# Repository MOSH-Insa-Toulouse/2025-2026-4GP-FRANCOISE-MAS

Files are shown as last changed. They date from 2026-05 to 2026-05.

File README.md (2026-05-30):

 # Capteur de déformation en graphite - Projet 4GP

  > **Génie Physique - INSA Toulouse - Promotion 2025-2026**
  > UF « Du capteur au banc de test »

  ## Sommaire
  - [Présentation générale](#présentation-générale)
  - [1. Le capteur graphite](#1-le-capteur-graphite)
    - [1.1 Principe physique](#11-principe-physique)
    - [1.2 Objectifs et livrables](#12-objectifs-et-livrables)
    - [1.3 Matériel](#13-matériel)
  - [2. Conditionnement du signal](#2-conditionnement-du-signal)
    - [2.1 Étage transimpédance (LTSpice)](#21-étage-transimpédance-ltspice)
    - [2.2 Modèle mathématique](#22-modèle-mathématique)
  - [3. Carte électronique (shield Arduino)](#3-carte-électronique-shield-arduino)
    - [3.1 Routage sous KiCad](#31-routage-sous-kicad)
    - [3.2 Fabrication et brochage](#32-fabrication-et-brochage)
  - [4. Logiciel embarqué](#4-logiciel-embarqué)
  - [5. Application mobile](#5-application-mobile)
  - [6. Banc de caractérisation](#6-banc-de-caractérisation)
  - [7. Résultats et analyse](#7-résultats-et-analyse)
  - [8. Bilan et perspectives](#8-bilan-et-perspectives)
  - [Remerciements](#remerciements)
  - [Contacts](#contacts)

  ---

  ## Présentation générale

  Ce projet propose une chaîne de mesure complète - acquisition, traitement, affichage et
  archivage des résultats - construite autour d'un capteur de déformation **low-tech** : une simple piste
  de graphite tracée au crayon sur du papier.

  L'ensemble s'appuie sur l'article de **Lin, C.-W., Zhao, Z., Kim, J. et al. (2014)**,
  *« Pencil Drawn Strain Gauges and Chemiresistors on Paper »* (Nature). L'article de
  référence est disponible dans le dépôt.

  On cherche ic à faire un dispositif **bon marché,
  reproductible, réparable et fabricable avec des moyens d'atelier ordinaires**, tout en
  restant exploitable scientifiquement.

  ---

  ## 1. Le capteur graphite

  ### 1.1 Principe physique

  Le capteur est obtenu en frottant un crayon sur une feuille de papier (≈ 0,35 mm
  d'épaisseur). Le graphite s'accroche aux fibres et forme un réseau granulaire : le
  courant circule par les contacts entre grains et par effet tunnel entre particules
  voisines. La résistance du tracé dépend donc directement de la distance entre grains.

  Lorsque le papier est plié, cette distance évolue :

  | Sollicitation | Effet sur le réseau | Résistance |
  |---------------|---------------------|------------|
  | **Traction**  | Les grains s'écartent | **augmente** |
  | **Compression** | Les grains se rapprochent | **diminue** |

  La sensibilité dépend de plusieurs facteurs : dureté de la mine, quantité de graphite
  déposée, géométrie du tracé, humidité et température ambiantes. Différentes duretés ont
  été testées (2H, HB, B, 3B, 4B, 6B) afin de comparer leur comportement.

  ### 1.2 Objectifs et livrables

  L'objectif est de remonter à l'angle de flexion (donc à la déformation) à partir de la
  seule mesure de résistance. Le travail se décompose en cinq étapes : simulation du
  conditionnement analogique, conception du PCB, programmation du microcontrôleur,
  développement de l'application mobile et caractérisation expérimentale.

  Livrables produits :
  - un **shield Arduino** regroupant l'électronique de mesure, d'amplification et de
    communication.
  - un **code Arduino (C++)** organisé en pseudo machine à états (car nous avons essayer mais ce n'est pas réellement une machine à état).
  - une **IHM (interface human machine) en format .py** de supervision et de tracé temps réel.
  - une **datasheet** récapitulant la caractérisation du capteur.

  ### 1.3 Matériel

  **Électronique**
  - Arduino UNO Rev 3
  - Amplificateur opérationnel LTC1050
  - Potentiomètre numérique SPI MCP41010 (10 kΩ, 256 pas)
  - Écran OLED 0,96" SSD1306 (I²C)
  - Encodeur rotatif KY-040
  - Module Bluetooth HC-05
  - Passifs : résistances (2×1 kΩ, 1×10 kΩ, 2×100 kΩ) et condensateurs (2×100 nF, 1×1 µF)
  - Pour comparaison : capteur de flexion commercial (Flex Sensor) + résistance de charge 47 kΩ

  **Fabrication du capteur**
  - Papier souple, crayons de duretés variées, contacts et pinces de test Mueller

  **Logiciels**
  - LTSpice (simulation) · KiCad (PCB) · Arduino IDE (firmware)

  **Banc d'essai**
  - module imprimé en 3D à rayons de courbure étalonnés + instrumentation de mesure. Nous avons réutilisé les système imprimés les années passées pour rester dans la démarche **low-tech**

  ---

  ## 2. Conditionnement du signal

  ### 2.1 Étage transimpédance (LTSpice)

  À vide, le capteur affiche une résistance très élevée (du MΩ au GΩ selon la mine).
  Sous 5 V, le courant traversant n'est que de l'ordre du nanoampère : il faut donc un
  étage d'amplification pour ramener le signal dans la plage 0–5 V de l'ADC de l'Arduino.

  Un montage **transimpédance** autour du LTC1050 a été simulé sous LTSpice afin de valider
  le gain, étudier la réponse en fréquence et dimensionner le filtrage. Trois filtres
  passe-bas améliorent le rapport signal/bruit :

  1. **Entrée (~175 Hz)** — atténue les vibrations et tremblements mécaniques ;
  2. **Rétroaction active (~1,6 Hz)** — coupe le bruit secteur 50 Hz ;
  3. **Sortie (~1,6 kHz)** — supprime les parasites haute fréquence de l'électronique
     numérique.

  <p align="center">
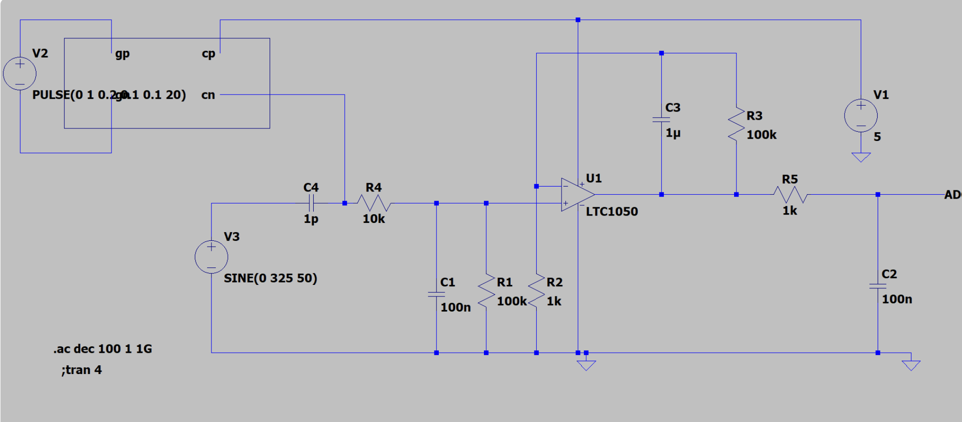
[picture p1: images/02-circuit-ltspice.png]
Schéma du montage transimpédance simulé sous LTSpice
    
    <br><em>Montage transimpédance autour du LTC1050 simulé sous LTSpice.</em>
  </p>

  ### 2.2 Modèle mathématique

  La tension lue par l'ADC s'écrit :

  $$V_{ADC} = \left(1 + \frac{R_3}{R_2}\right) \cdot \frac{R_1}{R_1 + R_c + R_5} \cdot V_{cc}$$

  ce qui permet au firmware de remonter à la résistance du capteur :

  $$R_c = \left(1 + \frac{R_3}{R_2}\right) \cdot R_1 \cdot \frac{V_{cc}}{V_{ADC}} - R_1 - R_5$$

  La résistance $R_2$ est pilotée dynamiquement par le potentiomètre numérique MCP41010,
  ce qui rend possible l'auto-calibration décrite plus bas.

  ---

  ## 3. Carte électronique (shield Arduino)

  ### 3.1 Routage sous KiCad

  Une fois le montage validé en simulation, le PCB a été dessiné sous KiCad pour se
  brancher directement sur l'Arduino UNO. Il a fallu créer les symboles et empreintes des
  composants absents des bibliothèques standard (Bluetooth, potentiomètre numérique…),
  puis assembler le schéma en respectant les bus **SPI** et **I²C**.

  Le placement a cherché à raccourcir les pistes analogiques et à limiter les couplages.

  <p align="center">
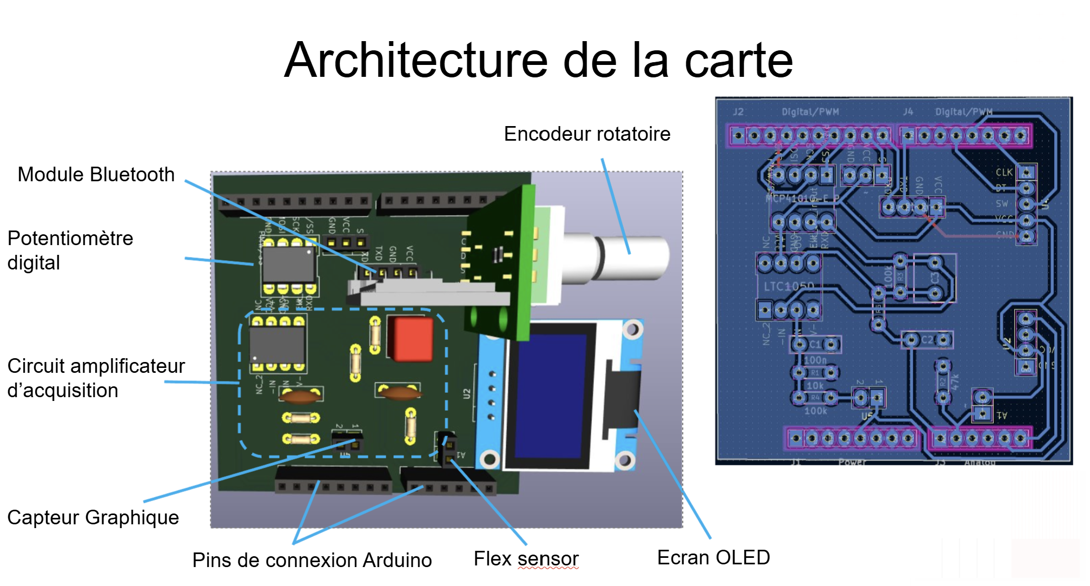
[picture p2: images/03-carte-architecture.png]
Architecture de la carte : rendu 3D annoté et routage PCB sous KiCad
    
    <br><em>Architecture de la carte : rendu 3D annoté (gauche) et routage du PCB sous KiCad (droite).</em>
  </p>

  ### 3.2 Fabrication et brochage

  Le circuit a été gravé sur plaque époxy cuivrée par **photolithographie**
  (impression du masque, insolation UV, révélation, gravure au perchlorure de fer,
  perçage, soudure). *Merci à Cathy sans qui on serait sans doute encore en train de nous arracher les cheveux sur la carte.*

  Brochage retenu :

  | Composant | Rôle | Interface Arduino |
  |-----------|------|-------------------|
  | LTC1050 | Amplification transimpédance | Entrée analogique `A0` |
  | MCP41010 | Potentiomètre numérique 10 kΩ | SPI (`CS`, `MOSI: D11`, `SCK: D13`) |
  | SSD1306 | Affichage OLED | I²C (`SDA: A4`, `SCL: A5`) |
  | KY-040 | Navigation menu | Interruptions (`CLK: D2`, `DT`, `SW`) |
  | HC-05 | Liaison Bluetooth | SoftwareSerial (`RX`, `TX`) |
  | Flex Sensor | Référence commerciale | Pont diviseur (47 kΩ) |

  Des tests de continuité et de courts-circuits ont suivi l'assemblage. Une première carte
  a dû être reprise : car nous nous étions trompé avec le port qui était nécessaire aux interruptions pour le menu.

  ---

  ## 4. Logiciel embarqué

  Le firmware Arduino orchestre l'ensemble du système au moyen d'une **tentative de code de machine à états**,
  ce qui garantit un enchaînement clair des tâches :

  Fonctions principales : acquisition du signal, calcul de $R_c$, **auto-calibration** de
  la résistance à plat $R_0$ via le MCP41010 (point de repos centré à $V_{cc}/2$),
  affichage OLED, navigation par encodeur (gérée par interruptions) et transmission
  Bluetooth. Le code s'appuie sur les bibliothèques SPI, I²C et série, avec un soin
  particulier porté à la stabilité des mesures.

  ---

  ## 5. Application mobile

  Une application Android développée avec claude code dans un premier temps mais nous nous sommes rendu compte que le code était bine trop complexe pour une app qui reste assez basique. Alors nous nous sommes tournés vers une HIM python car avec nos expériences personnelles nous avions déjà été confronté à ce genre de code python pour assurer la supervision et
  l'archivage des mesures :

  - connexion au module HC-05 (sélection dans la liste, voyant d'état) ;
  - réception cadencée sur un timer de 200 ms (5 Hz) dès que des octets sont disponibles ;
  - tracé temps réel par défilement horizontal sur un `Canvas` ;
  - export des données au format `.txt` (concaténation dans une variable globale, puis
    `SaveFile`).

  L'objectif était de disposer d'une interface simple, utilisable directement pendant les
  essais.

  <p align="center">
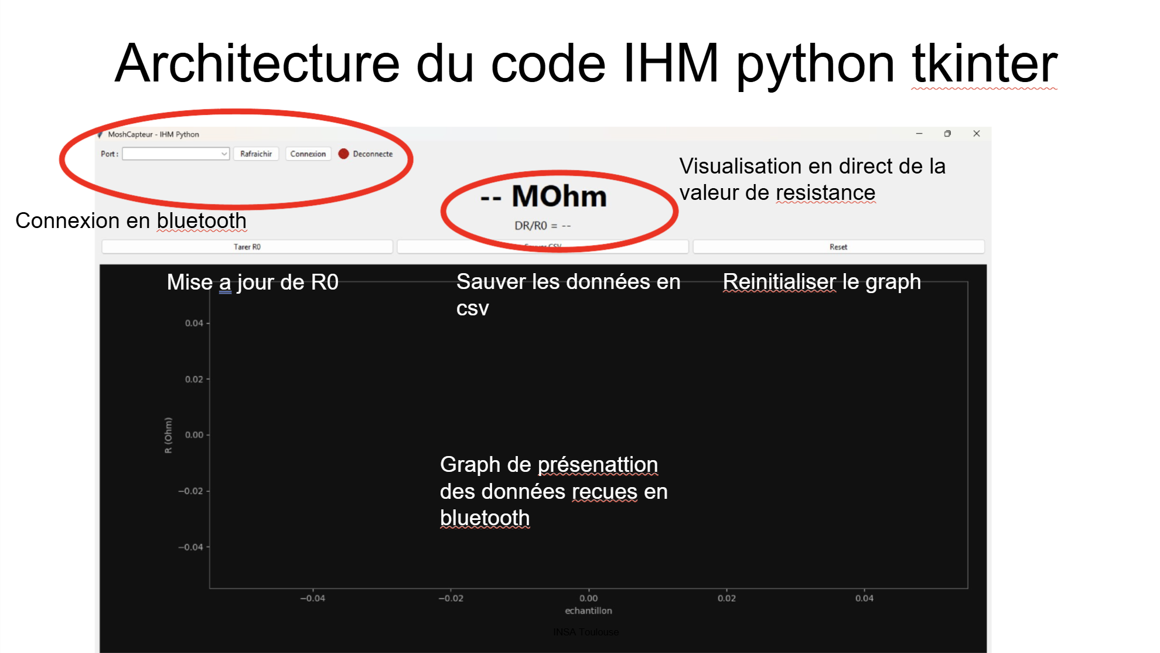
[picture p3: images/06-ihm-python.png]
Interface de supervision IHM en Python
    
    <br><em>IHM Python : connexion HC-05, tracé temps réel et export des mesures.</em>
  </p>

  ---

  ## 6. Banc de caractérisation

  Pour imposer des déformations connues, un **gabarit imprimé en 3D** a été conçu : une
  série de demi-cylindres à rayons de courbure étalonnés. Le capteur, maintenu par des
  pinces de test, y est plaqué dans deux configurations :

  - **Traction** : la piste de graphite est orientée vers l'extérieur → le maillage
    s'étire → $R_c$ augmente.
  - **Compression** : la piste est plaquée contre le cylindre → les feuillets se
    rapprochent → $R_c$ diminue.

  Chaque rayon correspond à un angle de flexion connu, ce qui permet d'étudier la
  sensibilité, la répétabilité et la réponse traction/compression pour plusieurs duretés
  de crayon.

  <p align="center">
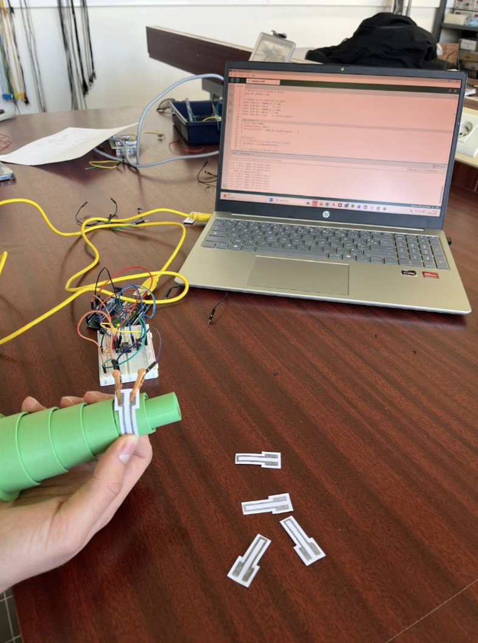
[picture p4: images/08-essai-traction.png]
Essai en traction sur le banc de caractérisation
    
    <br><em>Essai en traction : la piste de graphite est orientée vers l'extérieur.</em>
  </p>

  ---

  ## 7. Résultats et analyse

  Les mesures confirment le comportement attendu : **hausse de la résistance en traction,
  baisse en compression**, avec une forte dépendance au type de mine utilisé.

  - Les mines **tendres** (4B, 6B), riches en carbone, donnent une résistance initiale
    faible, une bonne conductivité et une réponse linéaire en compression — mais une faible
    tenue mécanique (perte de matière par frottement).
  - Les mines **plus dures** (B, 3B), plus chargées en liant, partent d'une résistance plus
    élevée et offrent un facteur de jauge supérieur, au prix d'une dérive et
    d'irrégularités caractéristiques des milieux granulaires désordonnés.

  On observe aussi que **la mesure abîme le capteur** : la résistance à plat diffère avant
  et après essai. Les acquisitions ont donc été menées en deux temps (traction puis
  compression), chacune avec sa propre *flat-band resistance*.

  <p align="center">
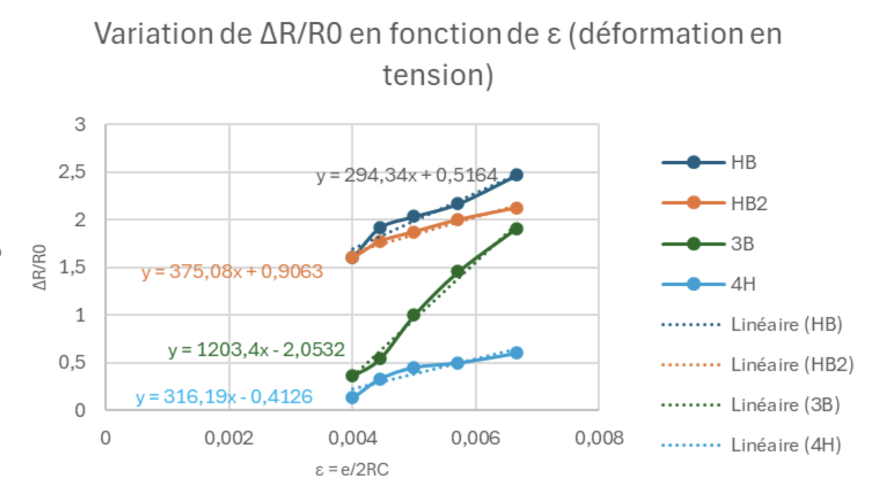
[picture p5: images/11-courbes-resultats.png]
Courbes R = f(flexion) en traction et compression
    
    <br><em>Courbes R = f(flexion/compression) pour les différentes mines.</em>
  </p>

  ---

  ## 8. Bilan et perspectives

  Le projet valide une **chaîne de mesure complète et connectée**, de la modélisation
  analogique jusqu'à l'application mobile, à partir de matériaux quasi gratuits.

  **Atouts** : coût matière négligeable, éco-conception, accessibilité, bonne réponse en
  traction/compression, faible consommation, capteur réparable sur place en repassant du
  graphite.

  **Limites** : répétabilité modeste (usure du film, contacts des pinces, hystérésis du
  papier) face aux jauges industrielles.

  Le capteur reste **exploitable à condition d'être calibré individuellement** : les
  valeurs absolues varient, mais le comportement relatif sous déformation est cohérent
  après étalonnage.

  Pistes d'amélioration vers un produit viable (capteurs jetables, usage pédagogique) :
  1. **électrodes fixes** imprimées plutôt que des contacts mécaniques ;
  2. **protection** du film par vernis/plastification, et vernis sur le PCB contre
     l'oxydation du cuivre.

  ---

  ## Remerciements

  Merci à l'équipe encadrante pour son accompagnement durant les phases de conception, de
  fabrication et de caractérisation : **J. Grisolia, B. Mestre, A. Biganzoli et
  C. Crouzet** — et tout particulièrement à Cathy Crouzet pour son aide en atelier PCB.

  ## Contacts

  N'hésitez pas à nous écrire pour toute question sur le projet ou les fichiers de
  fabrication :

  - **Ellande FRANCOISE** — `francoise@insa-toulouse.fr`
  - **Clément MAS** — `cmas@insa-toulouse.fr`

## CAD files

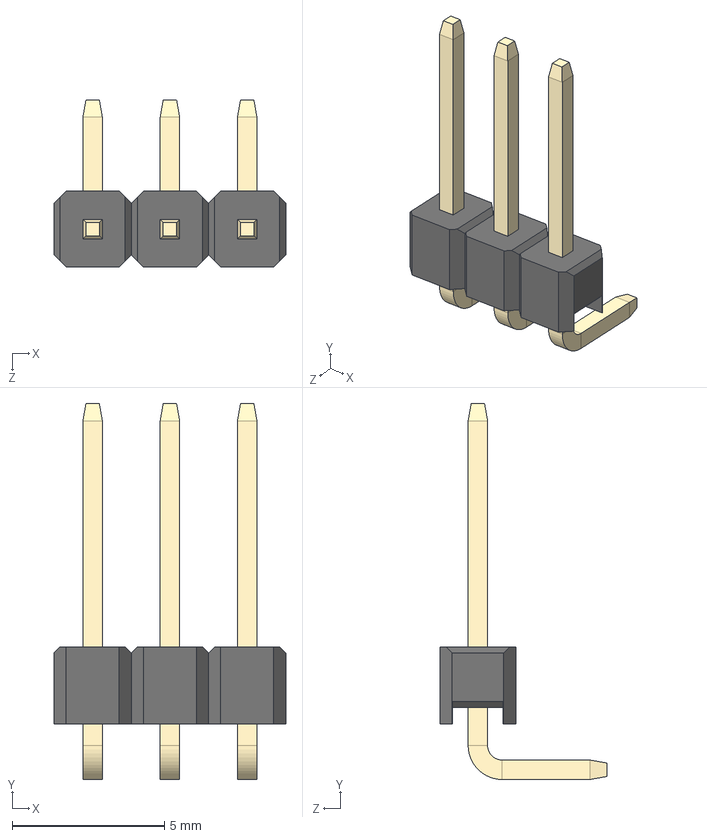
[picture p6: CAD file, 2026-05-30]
KICAD/Projet Capteur final/Composants/1x3 Male Pin Header Angle.STEP
7.63 x 12.4 x 5.50 mm

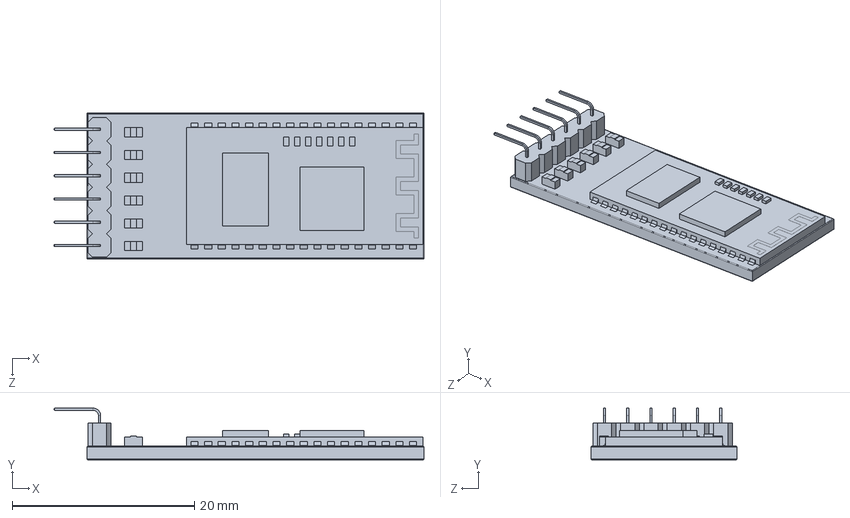
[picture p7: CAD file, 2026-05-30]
KICAD/Projet Capteur final/Composants/HC05.STEP
40.6 x 5.67 x 16.0 mm

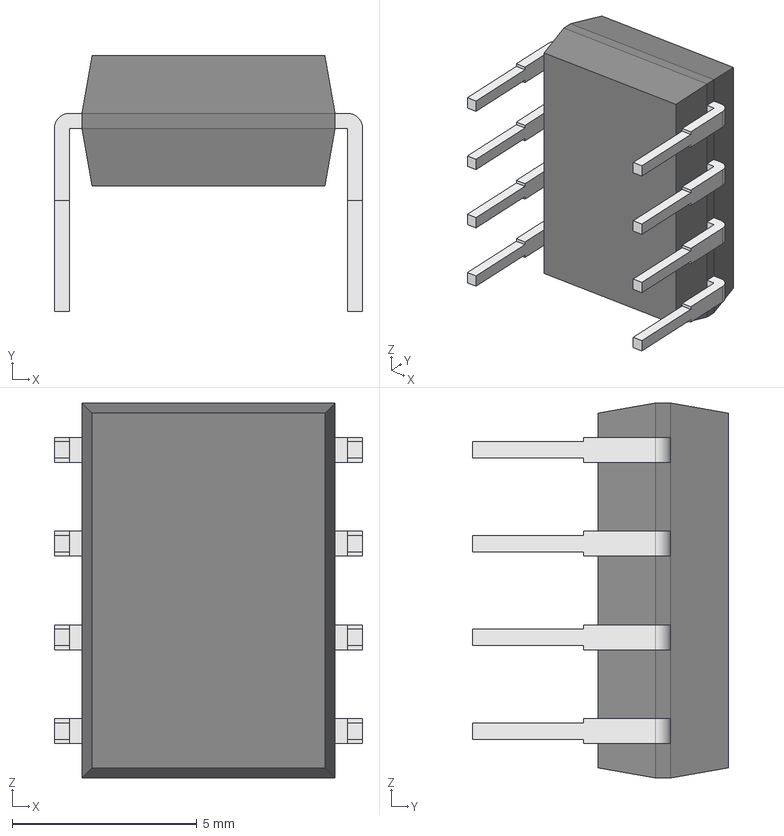
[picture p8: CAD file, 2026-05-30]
KICAD/Projet Capteur final/Composants/LTC1050ACN8.step
8.35 x 6.93 x 10.2 mm
Body001 (Mirror #1) x 5

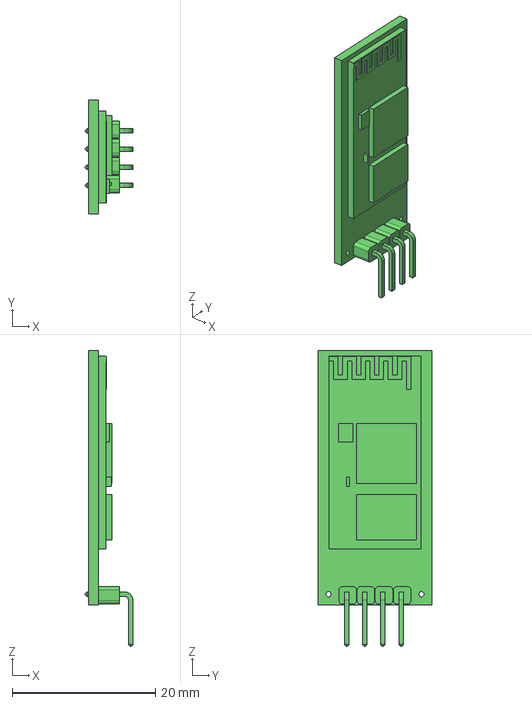
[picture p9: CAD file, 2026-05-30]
KICAD/Projet Capteur final/Composants/HC-05 Bluetooth Module.stp
6.68 x 16.0 x 41.4 mm

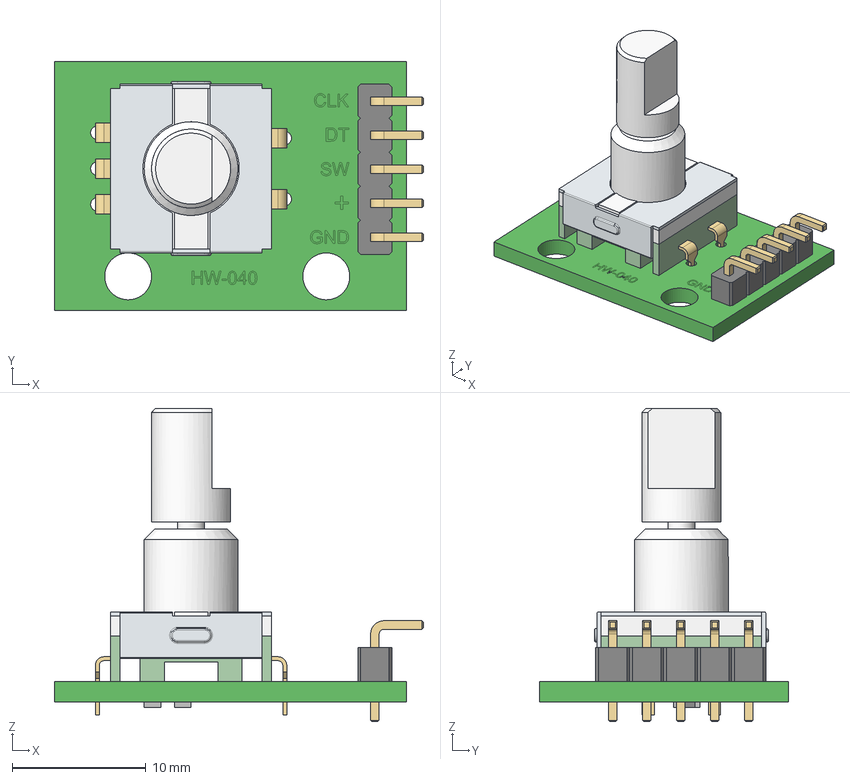
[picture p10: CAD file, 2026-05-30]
KICAD/Projet Capteur final/Composants/HW-040 Encoder module.stp
27.6 x 18.6 x 23.4 mm
Encoder PCB
Knob static part
Knob rotary part
Top plate knob
Plastic bottom knob
Encoder terminal x 5
1X5 Pin Socket
Bend pin x 5
0805 Terminal x 4
0805 Resistor Body x 2

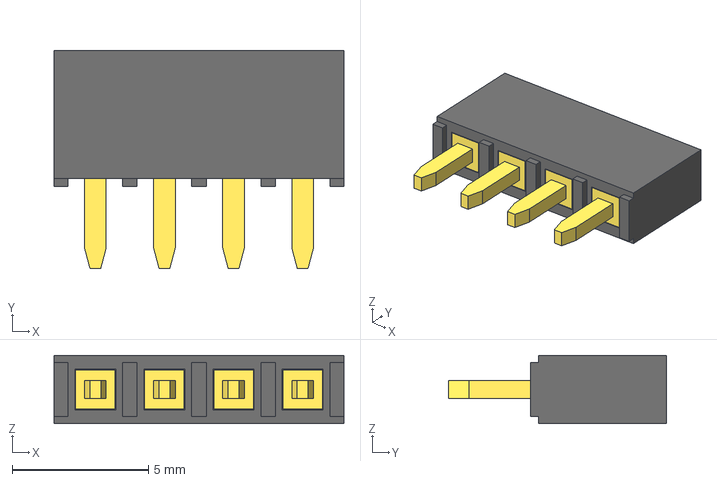
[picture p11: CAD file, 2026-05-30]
KICAD/Projet Capteur final/Composants/4-Pin Header - Female - 2.54mm (1).step
10.7 x 8.00 x 2.50 mm

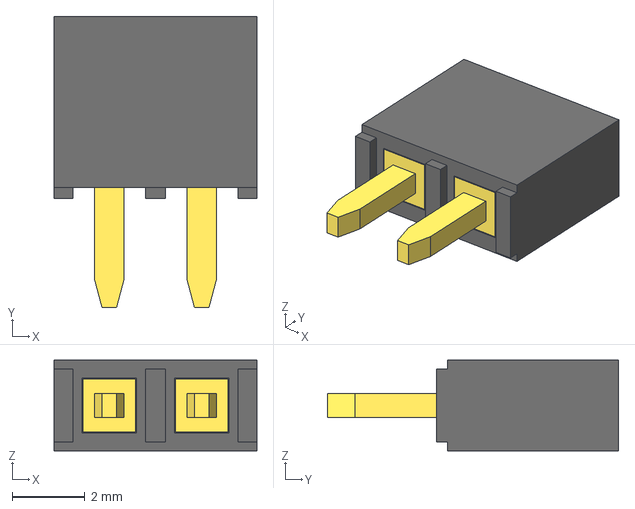
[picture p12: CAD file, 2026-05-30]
KICAD/Projet Capteur final/Composants/2-Pin Header - Female - 2.54mm.step
5.58 x 8.00 x 2.50 mm

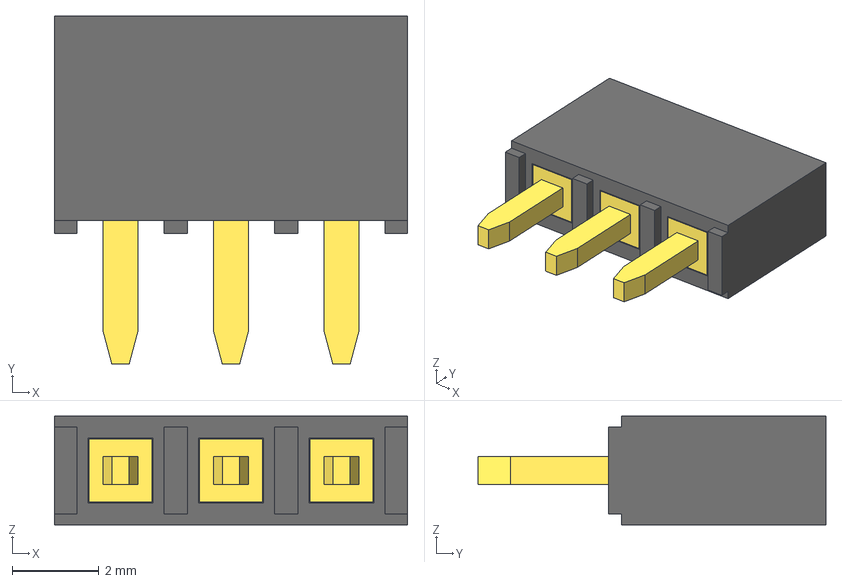
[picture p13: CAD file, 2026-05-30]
KICAD/Projet Capteur final/Composants/3-Pin Header - Female - 2.54mm.step
8.12 x 8.00 x 2.50 mm

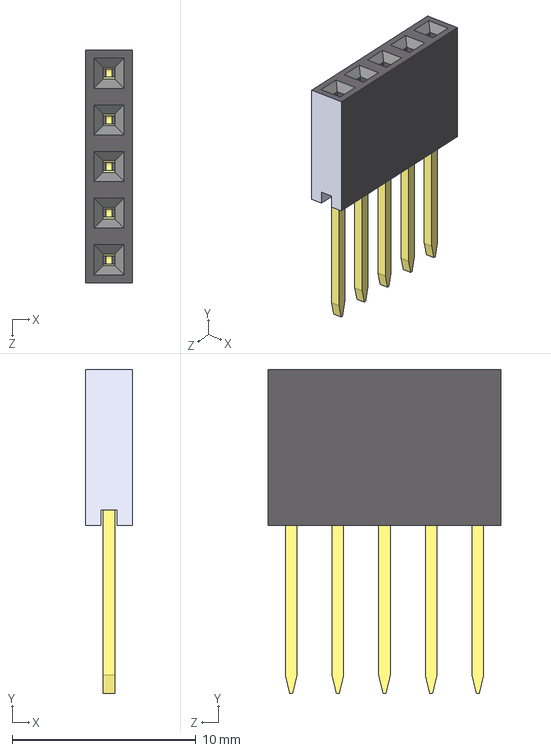
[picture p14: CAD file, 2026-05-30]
KICAD/Projet Capteur final/Composants/1x5.STEP
2.54 x 17.6 x 12.7 mm

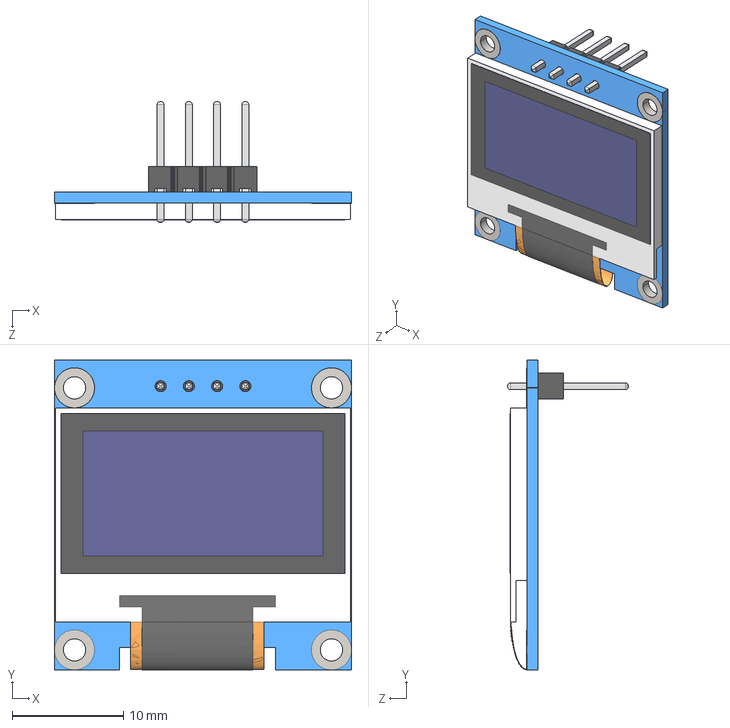
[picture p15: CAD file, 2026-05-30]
KICAD/Projet Capteur final/Composants/OLED 128x64.STP
26.7 x 27.9 x 10.8 mm

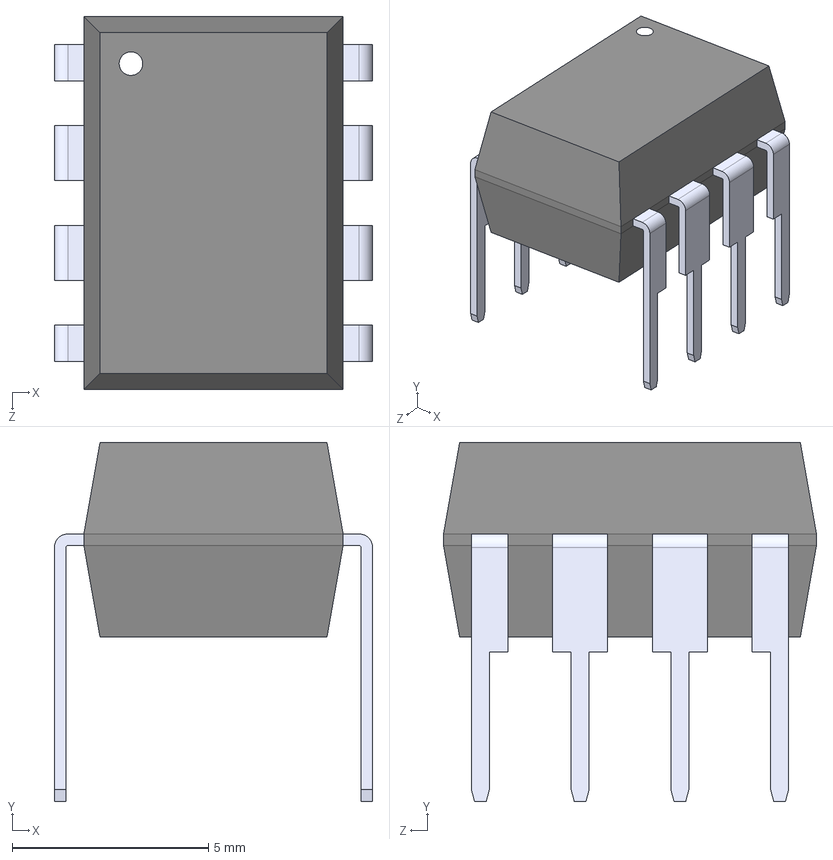
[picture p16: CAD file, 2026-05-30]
KICAD/Projet Capteur final/Composants/MCP41010-E_P.step
8.10 x 9.14 x 9.50 mm

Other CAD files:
KICAD/Projet Capteur final/Composants/HC05.SLDPRT

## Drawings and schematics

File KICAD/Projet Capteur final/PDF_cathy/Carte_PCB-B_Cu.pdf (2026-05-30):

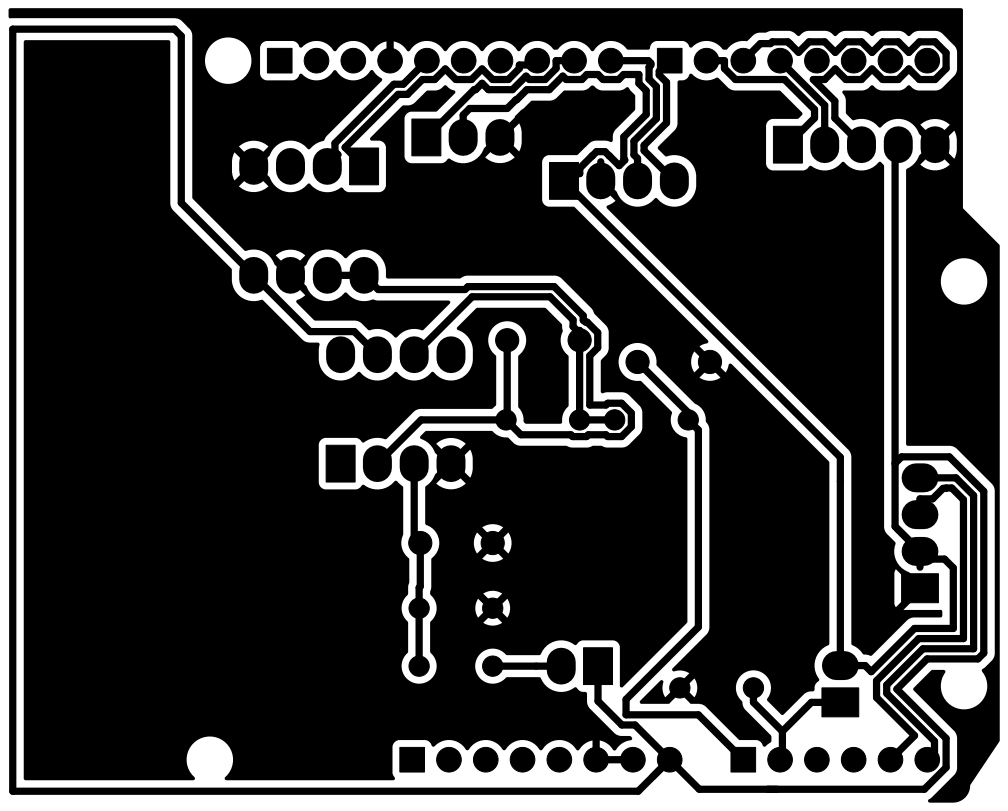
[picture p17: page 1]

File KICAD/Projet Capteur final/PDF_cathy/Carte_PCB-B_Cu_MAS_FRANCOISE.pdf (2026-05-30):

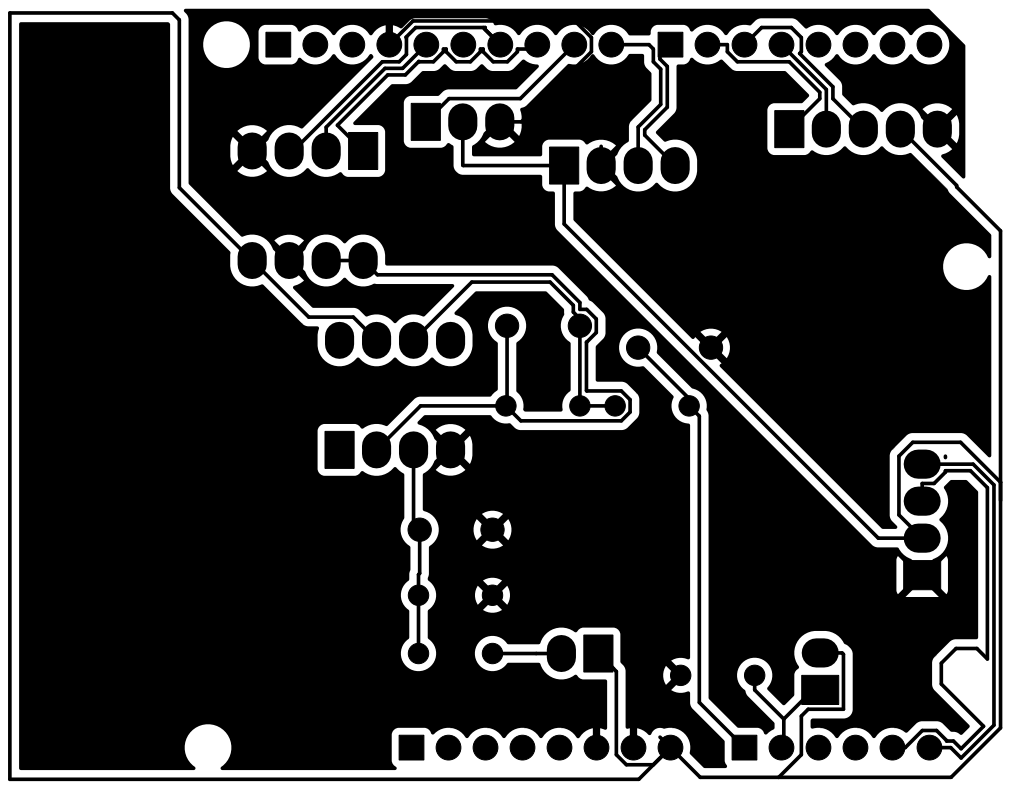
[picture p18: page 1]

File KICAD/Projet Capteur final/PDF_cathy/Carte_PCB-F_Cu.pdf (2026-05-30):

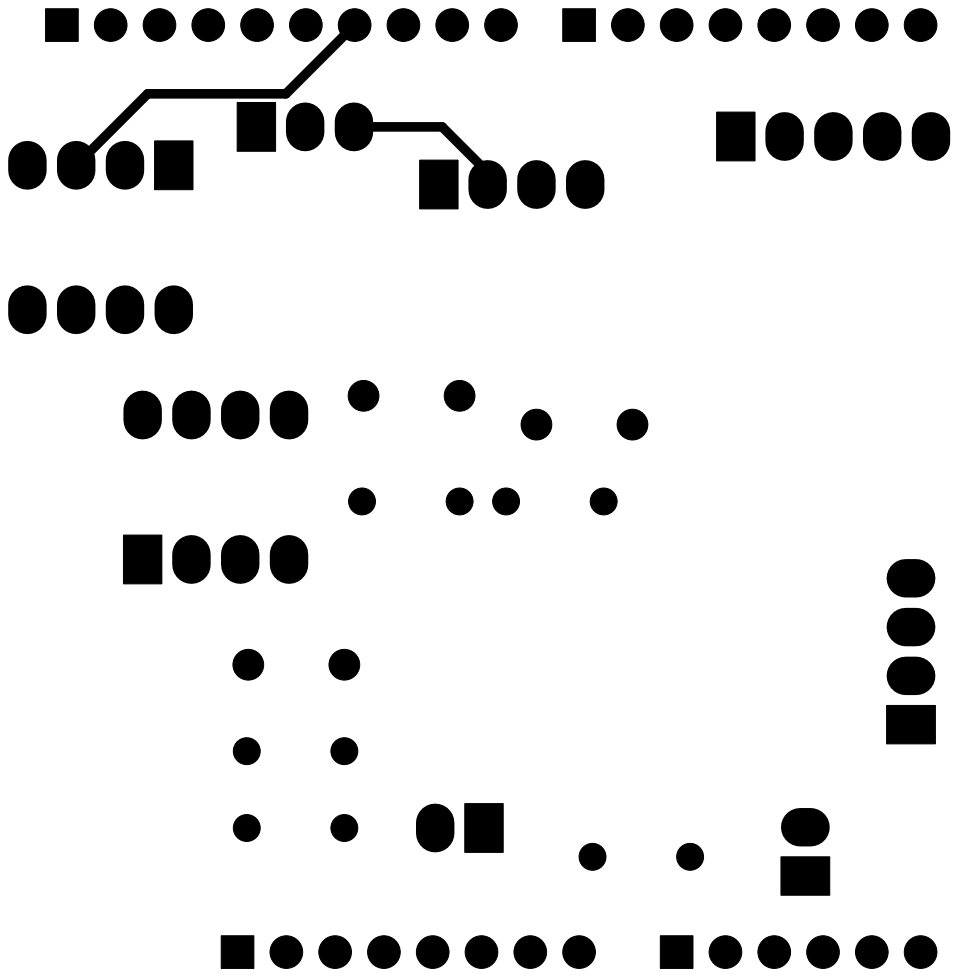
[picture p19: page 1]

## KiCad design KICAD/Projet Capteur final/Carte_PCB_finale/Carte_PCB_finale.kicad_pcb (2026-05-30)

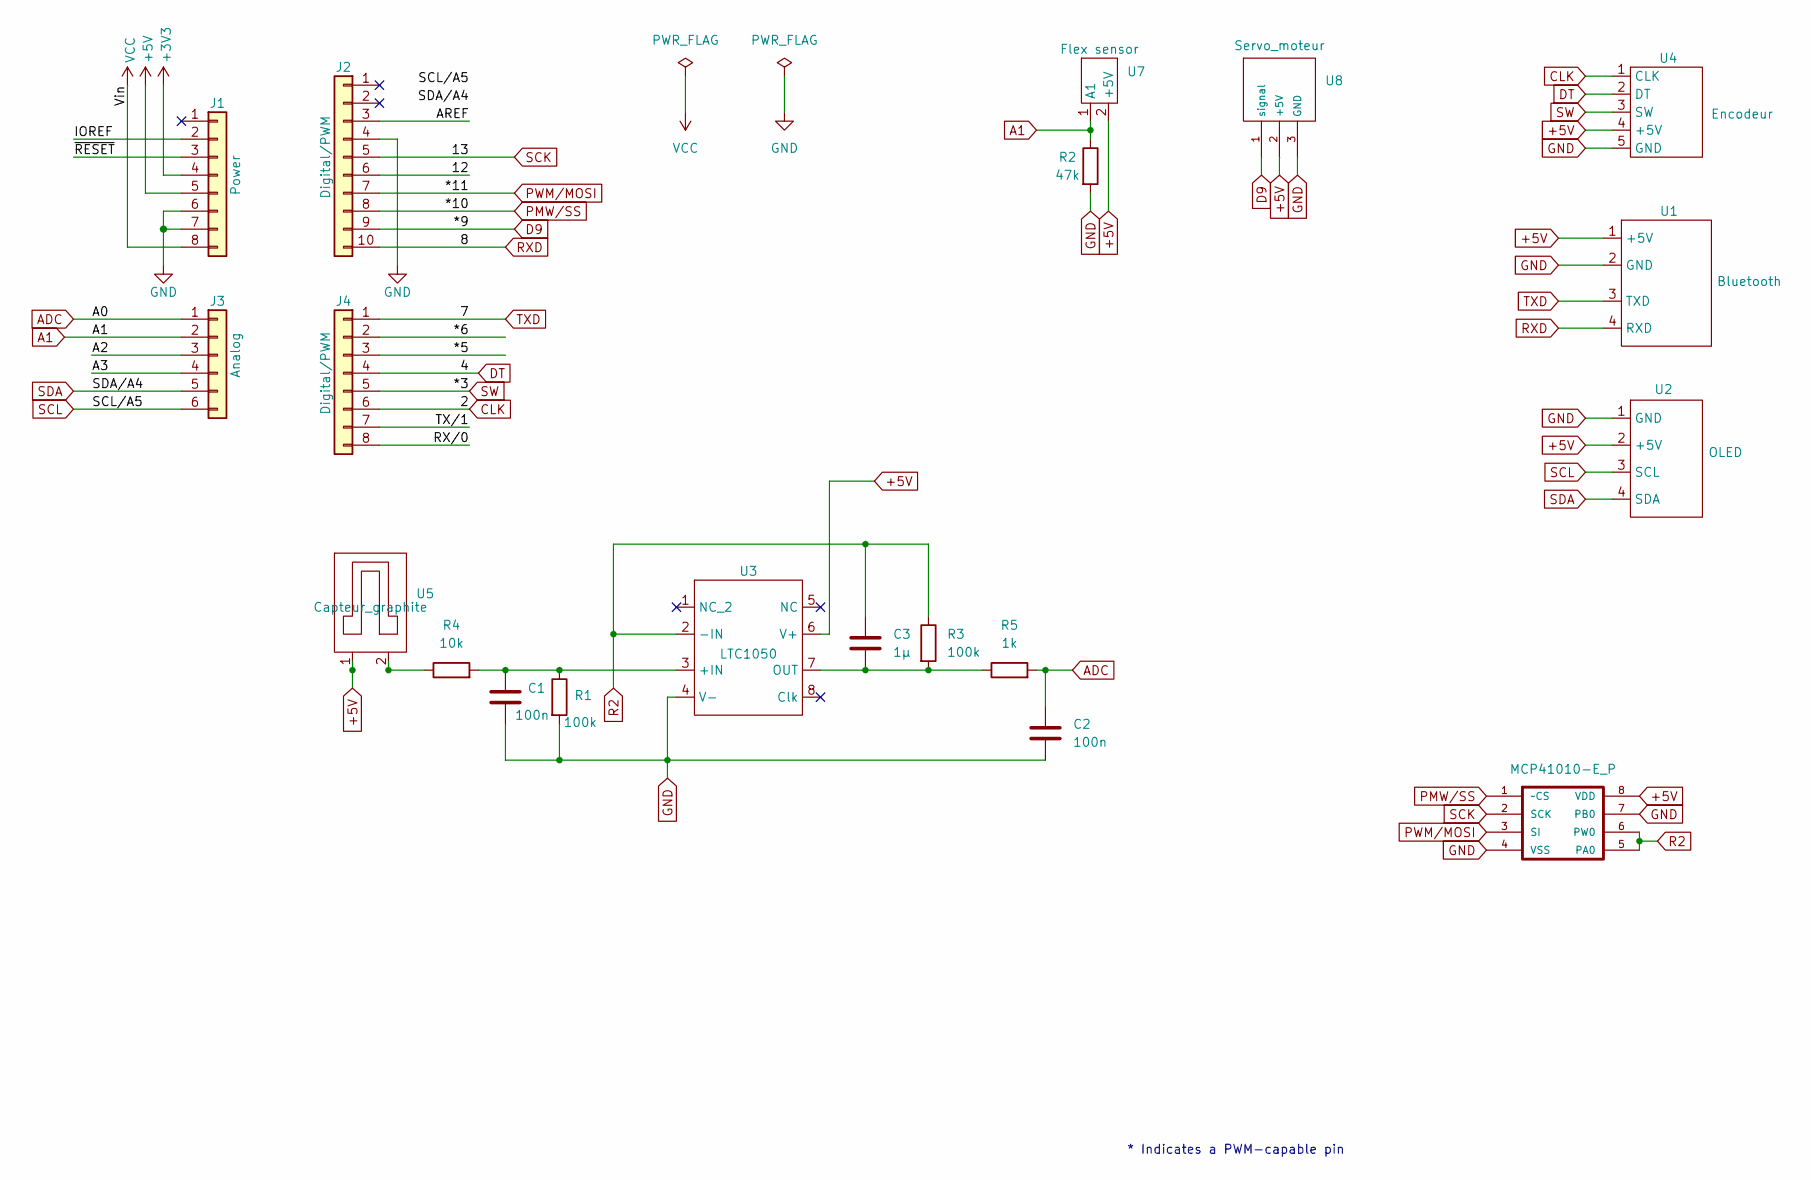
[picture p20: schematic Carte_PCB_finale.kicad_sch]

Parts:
C1, C2: 100n; C_Disc_D8.0mm_W2.5mm_P5.00mm
C3: 1µ; C_Rect_L7.5mm_W6.5mm_P5.00mm
J1: Power; PinSocket_1x08_P2.54mm_Vertical
J2: Digital/PWM; PinSocket_1x10_P2.54mm_Vertical
J3: Analog; PinSocket_1x06_P2.54mm_Vertical
J4: Digital/PWM; PinSocket_1x08_P2.54mm_Vertical
R1, R3: 100k; R_Axial_DIN0204_L3.6mm_D1.6mm_P5.08mm_Horizontal
R2: 47k; R_Axial_DIN0204_L3.6mm_D1.6mm_P5.08mm_Horizontal
R4: 10k; R_Axial_DIN0204_L3.6mm_D1.6mm_P5.08mm_Horizontal
R5: 1k; R_Axial_DIN0204_L3.6mm_D1.6mm_P5.08mm_Horizontal
U1: Empreinte_bluetooth
U2: empreinte_oled
U3: Empreinte_LTC1050
U4: Empreinte_encodeur
U5: Capteur_graphite
U6: MCP41010-E_P; MCP4101
U7: Flex_sensor
U8: empreinte_servo_moteur

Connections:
+3V3: J1.4
+5V: J1.5, U1.1 (+5V), U2.2 (+5V), U3.6 (V+), U4.4 (+5V), U5.1, U6.8 (VDD), U7.2 (+5V), U8.2 (+5V)
/12: J2.6
/*5: J4.3
/*6: J4.2
/A2: J3.3
/A3: J3.4
/AREF: J2.3
/IOREF: J1.2
/RX/0: J4.8
/TX/1: J4.7
/~RESET: J1.3
A1: J3.2, R2.1, U7.1 (A1)
ADC: C2.1, J3.1, R5.2
CLK: J4.6, U4.1 (CLK)
D9: J2.9, U8.1 (signal)
DT: J4.4, U4.2 (DT)
GND: C1.2, C2.2, J1.6, J1.7, J2.4, R1.2, R2.2, U1.2 (GND), U2.1 (GND), U3.4 (V-), U4.5 (GND), U6.4 (VSS), U6.7 (PB0), U8.3 (GND)
unnamed: R4.1, U5.2
unnamed: C1.1, R1.1, R4.2, U3.3 (+IN)
unnamed: C3.2, R3.2, R5.1, U3.7 (OUT)
PMW/SS: J2.8, U6.1 (~CS)
PWM/MOSI: J2.7, U6.3 (SI)
R2: C3.1, R3.1, U3.2 (-IN), U6.5 (PA0), U6.6 (PW0)
RXD: J2.10, U1.4 (RXD)
SCK: J2.5, U6.2 (SCK)
SCL: J3.6, U2.3 (SCL)
SDA: J3.5, U2.4 (SDA)
SW: J4.5, U4.3 (SW)
TXD: J4.1, U1.3 (TXD)
VCC: J1.8

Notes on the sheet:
* Indicates a PWM-capable pin

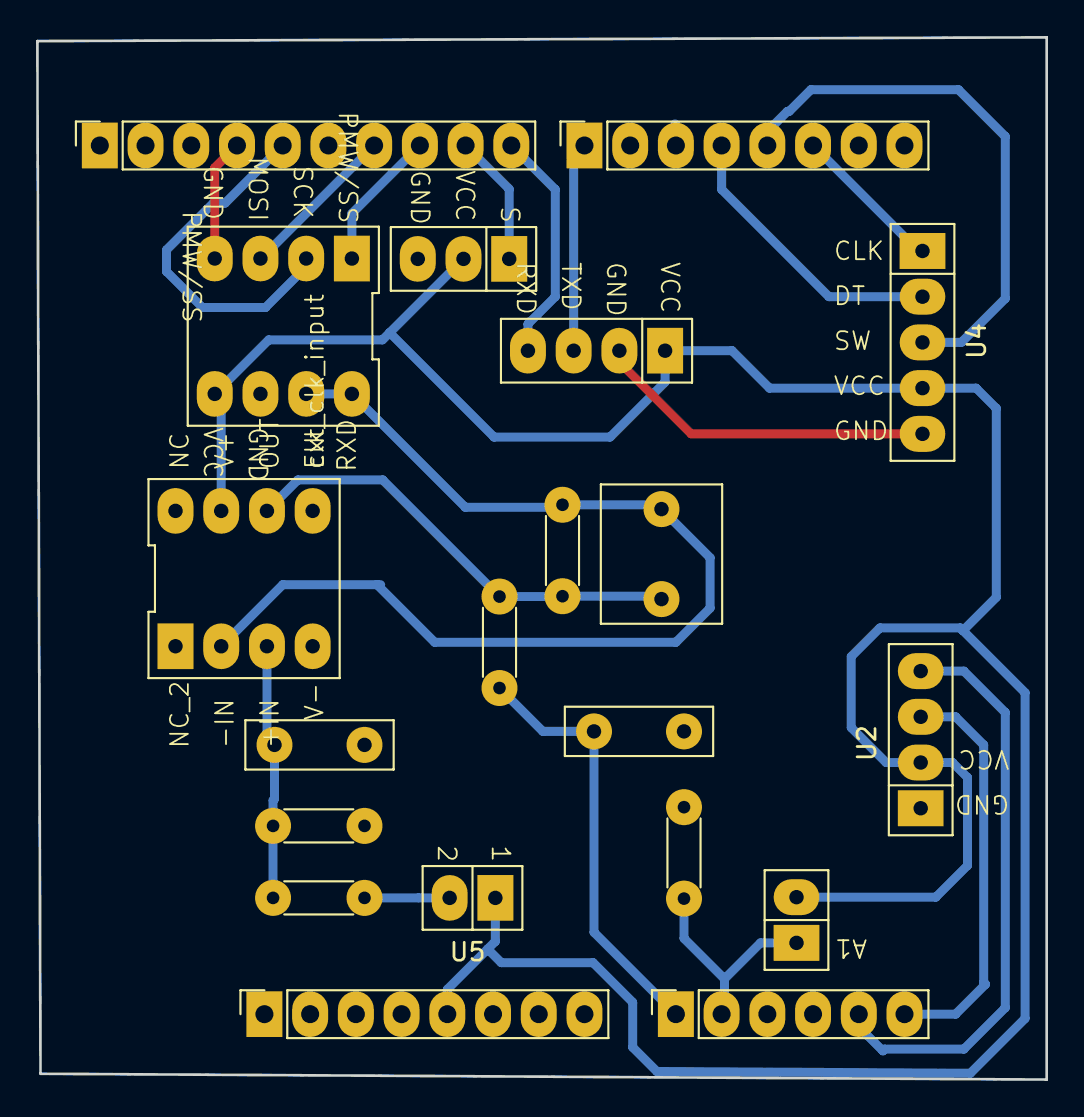
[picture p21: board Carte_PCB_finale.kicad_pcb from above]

Board: 2 copper layers, 56.1 x 57.9 mm, 20 parts (0 on the bottom side), 19 nets.

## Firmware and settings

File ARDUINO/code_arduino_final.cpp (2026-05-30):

/*
 * MOSH_Capteur — Projet 4GP INSA Toulouse
 * Reconstruit à partir de mes propres briques :
 *   - potentiometre_digital/tp4_F.ino     (MCP41050 SPI)
 *   - ecran_oled/tp4_ecran.ino            (SSD1306 I2C)
 *   - flex_sensor/tp3d.cpp                (flex + map)
 *   - encodeur_rotatif_interrupt/tp3g.ino (encodeur par interrupt)
 *   - bluetooth/tp1e.ino                  (SoftwareSerial HC-05)
 *   - blink_without_delay/tp1b.ino        (timing non-bloquant)
 *
 */

#include <SPI.h>  // pour piloter le potentiomètre digital (MCP41050) via SPI
#include <Wire.h>  //pilote le bus I2C (broches A4 SDA, A5 SCL) pour l'écran OLED
#include <SoftwareSerial.h>
#include <Adafruit_SSD1306.h> // driver haut niveau pour l'écran OLED

// ==============================================================
//  CONSTANTES — OLED (style ecran_oled/tp4_ecran.ino)
// ==============================================================
#define nombreDePixelsEnLargeur  128 //instancier l ecran oled avec resoltion
#define nombreDePixelsEnHauteur  64  //instancier l ecran oled avec resoltion
#define brocheResetOLED          -1 //pas de broche reset dédiée
#define adresseI2CecranOLED      0x3C //adresse I2C

Adafruit_SSD1306 ecranOLED(nombreDePixelsEnLargeur, nombreDePixelsEnHauteur, &Wire, brocheResetOLED);

// ==============================================================
//  CONSTANTES — POTENTIOMÈTRE DIGITAL (tp4_F.ino)
// ==============================================================
const byte csPin        = 10; // est la broche Chip Select : quand on la met à LOW, il écoute le bus SPI, quand elle est HIGH il ignore les données
const int  maxPositions = 256; // le potentiomètre numérique à 256 positions
const long rAB          = 92500;   // ajusté au multimètre
const byte rWiper       = 125;  //résistance résiduelle du curseur interne quand la position est à 0
const byte pot0         = 0x11;    // adresse potentiomètre 0

// ==============================================================
//  CONSTANTES — FLEX SENSOR (tp3d.cpp)
// ==============================================================
const int   flexPin         = A1;
const float VCC             = 5.0;
const float R_DIV           = 22000.0; // résistance de diviseur de tension
const float flatResistance  = 20300.0; //resistance en position plate mesuré par nous meme
const float bendResistance  = 50200.0; // resistance en potition pliée à 90 degrés mesuré par nous meme

// ==============================================================
//  CONSTANTES — ENCODEUR (tp3g.ino)
// ==============================================================
#define encoder0PinA  2    // CLK 
#define encoder0PinB  4    // DT
#define Switch        3    // bouton OK

volatile int encoder0Pos = 0; //est modifiée dans la routine d'interruption  
//Sans volatile, le compilateur pourrait optimiser en gardant une copie en registre et ne jamais relire la vraie valeur en RAM
int lastEncoderPos       = 0;

// ==============================================================
//  CONSTANTES — BLUETOOTH (tp1e.ino)
// ==============================================================
#define rxPin     8        // RX ← HC-05 TX
#define txPin     7        // TX → HC-05 RX
#define baudrate  9600

SoftwareSerial mySerial(rxPin, txPin);

// ==============================================================
//  CONSTANTES — CAPTEUR GRAPHITE
// ==============================================================
#define PIN_GRAPHITE  A0
#define R1            100000.0
#define R3            100000.0
#define R5            1000.0

// ==============================================================
//  ÉTAT GLOBAL
// ==============================================================
uint8_t potPos          = 128; //est la position actuelle du curseur du potentiomètre digital initialisée au milieu de la plage
int     menuIndex       = 0; //ligne sélectionnée dans le menu
unsigned long lastMeas  = 0; //on compare millis() - lastMeas à un intervalle plutôt que d'appeler delay() pour éviter de bloquer le programme

enum State { MENU, MESURE, MOYENNE, FLEX, CALIB };
State state = MENU;

// ==============================================================
//  BRIQUE — POTENTIOMÈTRE DIGITAL (tp4_F.ino)
// ==============================================================
void setPotWiper(int addr, int pos) {
  pos = constrain(pos, 0, 255);
  digitalWrite(csPin, LOW);
  SPI.transfer(addr);
  SPI.transfer(pos);
  digitalWrite(csPin, HIGH);
}

float potResistance(int pos) {
  return ((float)rAB * pos / maxPositions) + rWiper; // formule ligne 36 tp4_F.ino, convertit la position du potentiomètre en résistance équivalente
}

// ==============================================================
//  BRIQUE — CAPTEUR GRAPHITE
// ==============================================================
float readGraphiteV() { //lecture ADC 
  return analogRead(PIN_GRAPHITE) * VCC / 1023.0;
}

float readGraphiteAvg(int n) { // moyenne sur n periode et 10ms d'intervalle pour réduire le bruit
  long sum = 0;
  for (int i = 0; i < n; i++) { sum += analogRead(PIN_GRAPHITE); delay(10); }
  return (float)sum / (float)n * VCC / 1023.0;
}

float calcResGraphite(float vadc) {
  if (vadc < 0.001) return -1.0;  //Le test vadc < 0.001 protège contre la division par zéro, et r > 0 filtre les résultats physiquement impossibles
  float r2   = potResistance(potPos);
  float gain = 1.0 + R3 / r2;
  float r    = R1 * gain * (VCC / vadc) - R1 - R5;
  return (r > 0) ? r : -1.0;
}

// ==============================================================
//  BRIQUE — FLEX SENSOR (tp3d.cpp)
// ==============================================================
float readFlexR() {
  int   ADCflex = analogRead(flexPin);
  float Vflex   = ADCflex * VCC / 1023.0;
  if (Vflex <= 0.001) return -1.0;
  return R_DIV * (VCC / Vflex - 1.0);
}

float readFlexAngle() {
  float Rflex = readFlexR();
  if (Rflex < 0) return 0;
  float angle = map(Rflex, flatResistance, bendResistance, 0, 90);
  return constrain(angle, 0, 90);
}

// ==============================================================
//  BRIQUE — ENCODEUR (ISR de tp3g.ino) + bouton SW
// ==============================================================
void doEncoder() {
  if (digitalRead(encoder0PinA) == HIGH && digitalRead(encoder0PinB) == HIGH) {
    encoder0Pos++; //front montant de A, si B est HIGH, les deux signaux sont en phase ==> incrémentation
  } else if (digitalRead(encoder0PinA) == HIGH && digitalRead(encoder0PinB) == LOW) {
    encoder0Pos--;//front montant de A, si B est LOW, les deux signaux sont en opposition de phase ==> décrémentation
  }
}

bool readSwitch() { //Si moins de 300 ms se sont écoulées depuis le dernier appui détecté, on ignore l'appui
  static unsigned long lastSW = 0;
  if (millis() - lastSW > 300 && digitalRead(Switch) == LOW) {
    lastSW = millis();
    return true;
  }
  return false;
}

// ==============================================================
//  BRIQUE — BLUETOOTH (tp1e.ino)
// ==============================================================
void btSend(float val, const char* unit) {
  mySerial.print(val, 2);
  mySerial.print(' ');
  mySerial.println(unit);
}

// ==============================================================
//  AFFICHAGE OLED
// ==============================================================
void showMenu() {
  const char* labels[] = {"Mesure instant.", "Mesure moyennee", "Flex sensor", "Calibration pot"};
  ecranOLED.clearDisplay();
  ecranOLED.setTextSize(1); ecranOLED.setTextColor(SSD1306_WHITE);
  ecranOLED.setCursor(0, 0); ecranOLED.print(F("== MENU =="));
  for (int i = 0; i < 4; i++) {
    ecranOLED.setCursor(0, 14 + i * 12);
    ecranOLED.print(i == menuIndex ? F("> ") : F("  "));
    ecranOLED.print(labels[i]);
  }
  ecranOLED.display();
}

void showGraphite(float r) {
  ecranOLED.clearDisplay();
  ecranOLED.setTextSize(1); ecranOLED.setTextColor(SSD1306_WHITE);
  ecranOLED.setCursor(0, 0);  ecranOLED.print(F("== GRAPHITE =="));
  ecranOLED.setCursor(0, 16); ecranOLED.print(F("R = "));
  ecranOLED.setTextSize(2);
  if (r < 0)         { ecranOLED.print(F("ERR")); }
  else if (r > 1e6)  { ecranOLED.print(r / 1e6, 2); ecranOLED.setTextSize(1); ecranOLED.print(F(" MOhm")); }
  else if (r > 1e3)  { ecranOLED.print(r / 1e3, 2); ecranOLED.setTextSize(1); ecranOLED.print(F(" kOhm")); }
  else               { ecranOLED.print(r, 0);       ecranOLED.setTextSize(1); ecranOLED.print(F(" Ohm"));  }
  ecranOLED.setTextSize(1);
  ecranOLED.setCursor(0, 40); ecranOLED.print(F("Pot: ")); ecranOLED.print(potPos); ecranOLED.print(F("/255"));
  ecranOLED.setCursor(0, 56); ecranOLED.print(F("[Clic] = retour"));
  ecranOLED.display();
}

void showFlex(float r, float angle) {
  ecranOLED.clearDisplay();
  ecranOLED.setTextSize(1); ecranOLED.setTextColor(SSD1306_WHITE);
  ecranOLED.setCursor(0, 0);  ecranOLED.print(F("== FLEX SENSOR =="));
  ecranOLED.setCursor(0, 16); ecranOLED.print(F("R = ")); ecranOLED.print(r / 1000.0, 1); ecranOLED.print(F(" kOhm"));
  ecranOLED.setCursor(0, 30); ecranOLED.print(F("Angle: "));
  ecranOLED.setTextSize(2); ecranOLED.print(angle, 1); ecranOLED.setTextSize(1); ecranOLED.print(F(" deg"));
  ecranOLED.setCursor(0, 56); ecranOLED.print(F("[Clic] = retour"));
  ecranOLED.display();
}

void showCalib() {
  ecranOLED.clearDisplay();
  ecranOLED.setTextSize(1); ecranOLED.setTextColor(SSD1306_WHITE);
  ecranOLED.setCursor(0, 0);  ecranOLED.print(F("== CALIBRATION =="));
  ecranOLED.setCursor(0, 16); ecranOLED.print(F("Pot: "));
  ecranOLED.setTextSize(2); ecranOLED.print(potPos); ecranOLED.setTextSize(1); ecranOLED.print(F(" /255"));
  ecranOLED.setCursor(0, 38); ecranOLED.print(F("Gain ampli:"));
  int w = map(potPos, 0, 255, 0, 120);
  ecranOLED.drawRect(0, 48, 124, 10, SSD1306_WHITE);
  ecranOLED.fillRect(2, 50, w, 6, SSD1306_WHITE);
  ecranOLED.setCursor(0, 60); ecranOLED.print(F("[Clic]=retour"));
  ecranOLED.display();
}

// ==============================================================
//  CALIBRATION AUTO (recherche coarse + fine sur setPotWiper)
// ==============================================================
void autoCalibrate() {
  ecranOLED.clearDisplay();
  ecranOLED.setCursor(0, 0); ecranOLED.print(F("Calibration auto..."));
  ecranOLED.display();

  int bestPos = 128, bestDelta = 9999;

  for (int p = 0; p < 256; p += 4) {
    setPotWiper(pot0, p); delay(30);
    int d = abs(analogRead(PIN_GRAPHITE) - 512);
    if (d < bestDelta) { bestDelta = d; bestPos = p; }
  }
  for (int p = max(0, bestPos - 4); p <= min(255, bestPos + 4); p++) {
    setPotWiper(pot0, p); delay(30);
    int d = abs(analogRead(PIN_GRAPHITE) - 512);
    if (d < bestDelta) { bestDelta = d; bestPos = p; }
  }

  potPos = bestPos;
  setPotWiper(pot0, potPos);

  ecranOLED.clearDisplay();
  ecranOLED.setCursor(0, 0);  ecranOLED.print(F("Calibration OK"));
  ecranOLED.setCursor(0, 16); ecranOLED.print(F("Pot = ")); ecranOLED.print(potPos);
  ecranOLED.display();
  delay(1500);
}

// ==============================================================
//  SETUP
// ==============================================================
void setup() {
  Serial.begin(baudrate);
  mySerial.begin(baudrate);

  // SPI + pot
  digitalWrite(csPin, HIGH);
  pinMode(csPin, OUTPUT);
  SPI.begin();

  // Encodeur (style tp3g.ino)
  pinMode(encoder0PinA, INPUT); digitalWrite(encoder0PinA, HIGH);
  pinMode(encoder0PinB, INPUT); digitalWrite(encoder0PinB, HIGH);
  pinMode(Switch,       INPUT); digitalWrite(Switch,       HIGH);
  attachInterrupt(0, doEncoder, RISING);

  // OLED (style tp4_ecran.ino : halt si échec)
  if (!ecranOLED.begin(SSD1306_SWITCHCAPVCC, adresseI2CecranOLED))
    while (1);
  ecranOLED.setTextSize(1); ecranOLED.setTextColor(SSD1306_WHITE);

  autoCalibrate();
  showMenu();
}

// ==============================================================
//  LOOP — machine à états
// ==============================================================
void loop() {
  // Détection rotation : comparaison encoder0Pos (modifié par ISR) / lastEncoderPos
  int delta = 0;
  noInterrupts();
  int current = encoder0Pos;
  interrupts();
  if (current != lastEncoderPos) {
    delta = (current > lastEncoderPos) ? 1 : -1;
    lastEncoderPos = current;
  }

  bool ok = readSwitch();

  switch (state) {

    case MENU:
      if (delta < 0) { menuIndex = (menuIndex == 0) ? 3 : menuIndex - 1; showMenu(); }
      if (delta > 0) { menuIndex = (menuIndex + 1) % 4;                   showMenu(); }
      if (ok) {
        if (menuIndex == 0) state = MESURE;
        if (menuIndex == 1) state = MOYENNE;
        if (menuIndex == 2) state = FLEX;
        if (menuIndex == 3) { state = CALIB; showCalib(); }
        lastMeas = 0;
      }
      break;

    case MESURE:
      if (ok) { state = MENU; showMenu(); break; }
      if (millis() - lastMeas >= 500) {
        lastMeas = millis();
        float r = calcResGraphite(readGraphiteV());
        showGraphite(r);
        btSend(r > 1e6 ? r / 1e6 : r > 1e3 ? r / 1e3 : r,
               r > 1e6 ? "MOhm"  : r > 1e3 ? "kOhm"  : "Ohm");
        Serial.print(F("R=")); Serial.print(r);
        Serial.print(F(" Pot=")); Serial.println(potPos);
      }
      break;

    case MOYENNE:
      if (ok) { state = MENU; showMenu(); break; }
      if (millis() - lastMeas >= 2500) {
        lastMeas = millis();
        float r = calcResGraphite(readGraphiteAvg(5));
        showGraphite(r);
        btSend(r / 1e6, "MOhm");
      }
      break;

    case FLEX:
      if (ok) { state = MENU; showMenu(); break; }
      if (millis() - lastMeas >= 500) {
        lastMeas = millis();
        float r = readFlexR();
        showFlex(r, readFlexAngle());
        btSend(r, "Ohm");
      }
      break;

    case CALIB:
      if (ok) { state = MENU; showMenu(); break; }
      if (delta < 0 && potPos < 255) { potPos++; setPotWiper(pot0, potPos); showCalib(); }
      if (delta > 0 && potPos > 0)   { potPos--; setPotWiper(pot0, potPos); showCalib(); }
      break;
  }
}

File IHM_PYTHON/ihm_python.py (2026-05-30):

"""
IHM Python equivalente a l'app Android MoshCapteur.

Lit des lignes "valeur unite" (ex: "1.23 MOhm", "500.00 kOhm", "250 Ohm")
depuis un port serie (HC-05 Bluetooth = port COM sortant sous Windows, ou
cable USB Arduino direct).

Dependances :
    pip install pyserial matplotlib
"""

import csv
import threading
import time
import tkinter as tk
from collections import deque
from tkinter import messagebox, filedialog, ttk

import serial
import serial.tools.list_ports
from matplotlib.backends.backend_tkagg import FigureCanvasTkAgg
from matplotlib.figure import Figure


BAUDRATE = 9600
MAX_POINTS = 300


class MoshIHM:
    def __init__(self, root: tk.Tk):
        self.root = root
        self.root.title("MoshCapteur - IHM Python")
        self.root.geometry("800x600")

        self.ser: serial.Serial | None = None
        self.running = False
        self.reader_thread: threading.Thread | None = None

        self.samples: list[tuple[float, float]] = []   # (t_s, R_ohm)
        self.values = deque(maxlen=MAX_POINTS)
        self.r0_ohm: float | None = None
        self.t0: float | None = None

        self._build_ui()
        self._refresh_ports()

    # -------------------- UI --------------------
    def _build_ui(self):
        top = ttk.Frame(self.root, padding=8)
        top.pack(fill=tk.X)

        ttk.Label(top, text="Port :").pack(side=tk.LEFT)
        self.port_var = tk.StringVar()
        self.port_combo = ttk.Combobox(top, textvariable=self.port_var, width=25)
        self.port_combo.pack(side=tk.LEFT, padx=4)
        ttk.Button(top, text="Rafraichir", command=self._refresh_ports).pack(side=tk.LEFT)

        self.btn_connect = ttk.Button(top, text="Connexion", command=self._toggle_connect)
        self.btn_connect.pack(side=tk.LEFT, padx=8)

        self.status_dot = tk.Canvas(top, width=20, height=20, highlightthickness=0)
        self.status_dot.pack(side=tk.LEFT)
        self._dot_id = self.status_dot.create_oval(2, 2, 18, 18, fill="#BB0000", outline="")
        self.status_label = ttk.Label(top, text="Deconnecte")
        self.status_label.pack(side=tk.LEFT, padx=4)

        self.value_label = ttk.Label(self.root, text="-- MOhm",
                                     font=("Segoe UI", 36, "bold"), anchor="center")
        self.value_label.pack(fill=tk.X, pady=(10, 0))

        self.delta_label = ttk.Label(self.root, text="DR/R0 = --",
                                     font=("Segoe UI", 14), anchor="center")
        self.delta_label.pack(fill=tk.X)

        btns = ttk.Frame(self.root, padding=8)
        btns.pack(fill=tk.X)
        ttk.Button(btns, text="Tarer R0", command=self._tare).pack(side=tk.LEFT, expand=True, fill=tk.X, padx=2)
        ttk.Button(btns, text="Sauver CSV", command=self._save_csv).pack(side=tk.LEFT, expand=True, fill=tk.X, padx=2)
        ttk.Button(btns, text="Reset", command=self._clear).pack(side=tk.LEFT, expand=True, fill=tk.X, padx=2)

        self.fig = Figure(figsize=(7, 3.5), facecolor="#111111")
        self.ax = self.fig.add_subplot(111, facecolor="#111111")
        self.ax.tick_params(colors="#BBBBBB")
        for s in self.ax.spines.values():
            s.set_color("#666666")
        self.line_plot, = self.ax.plot([], [], color="cyan", linewidth=1.5)
        self.ax.set_xlabel("echantillon", color="#BBBBBB")
        self.ax.set_ylabel("R (Ohm)", color="#BBBBBB")
        self.fig.tight_layout()

        self.canvas = FigureCanvasTkAgg(self.fig, master=self.root)
        self.canvas.get_tk_widget().pack(fill=tk.BOTH, expand=True, padx=8, pady=8)

        self.root.protocol("WM_DELETE_WINDOW", self._on_close)
        self.root.after(200, self._refresh_plot)

    # -------------------- Ports & connexion --------------------
    def _refresh_ports(self):
        ports = [p.device for p in serial.tools.list_ports.comports()]
        self.port_combo["values"] = ports
        if ports and not self.port_var.get():
            self.port_var.set(ports[0])

    def _toggle_connect(self):
        if self.running:
            self._disconnect()
        else:
            self._connect()

    def _connect(self):
        port = self.port_var.get().strip()
        if not port:
            messagebox.showwarning("Port", "Selectionne un port COM.")
            return
        try:
            self.ser = serial.Serial(port, BAUDRATE, timeout=1)
        except serial.SerialException as e:
            messagebox.showerror("Erreur connexion", str(e))
            return

        self.running = True
        self._set_status(True)
        self.btn_connect.config(text="Deconnexion")
        self.reader_thread = threading.Thread(target=self._read_loop, daemon=True)
        self.reader_thread.start()

    def _disconnect(self):
        self.running = False
        if self.ser:
            try:
                self.ser.close()
            except Exception:
                pass
        self.ser = None
        self._set_status(False)
        self.btn_connect.config(text="Connexion")

    def _set_status(self, connected: bool):
        color = "#00AA44" if connected else "#BB0000"
        self.status_dot.itemconfig(self._dot_id, fill=color)
        self.status_label.config(text="Connecte" if connected else "Deconnecte")

    # -------------------- Lecture serie --------------------
    def _read_loop(self):
        assert self.ser is not None
        while self.running:
            try:
                raw = self.ser.readline()
                if not raw:
                    continue
                line = raw.decode(errors="ignore").strip()
                if line:
                    self._handle_line(line)
            except Exception:
                break
        self.root.after(0, lambda: self._set_status(False))

    def _handle_line(self, line: str):
        parts = line.split()
        if len(parts) < 2:
            return
        try:
            v = float(parts[0].replace(",", "."))
        except ValueError:
            return
        unit = parts[1]
        factor = {"MOhm": 1e6, "kOhm": 1e3, "Ohm": 1.0}.get(unit)
        if factor is None:
            return

        ohm = v * factor
        t = time.time()
        if self.t0 is None:
            self.t0 = t
        self.samples.append((t - self.t0, ohm))
        self.values.append(ohm)

        def update():
            self.value_label.config(text=f"{v:.2f} {unit}")
            if self.r0_ohm and self.r0_ohm > 0:
                d = (ohm - self.r0_ohm) / self.r0_ohm * 100.0
                self.delta_label.config(
                    text=f"DR/R0 = {d:+.2f} %  (R0 = {self.r0_ohm:.2f} Ohm)"
                )

        self.root.after(0, update)

    # -------------------- Boutons --------------------
    def _tare(self):
        if not self.samples:
            messagebox.showinfo("Tare", "Aucune valeur recue.")
            return
        self.r0_ohm = self.samples[-1][1]
        messagebox.showinfo("Tare", f"R0 = {self.r0_ohm:.2f} Ohm")
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

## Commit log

2026-05-30 remplacement de licencre apache par GPL3.0
2026-05-30 version finale
    [1x3 Male Pin Header Angle.STEP, 1x5.STEP, 2-Pin Header - Female - 2.54mm.step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]
